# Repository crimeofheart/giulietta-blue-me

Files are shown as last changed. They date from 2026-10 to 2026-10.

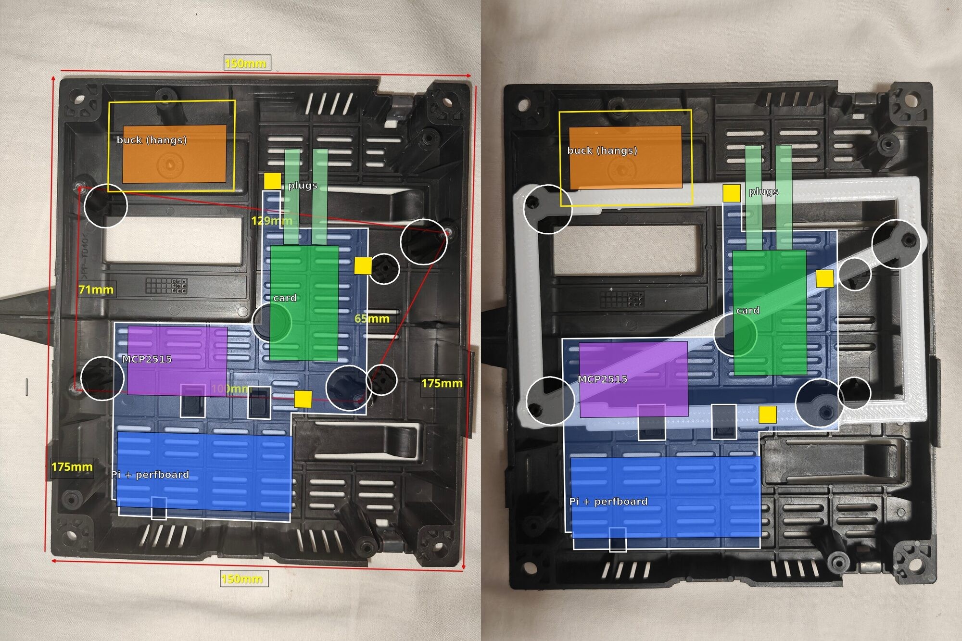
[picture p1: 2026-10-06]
hardware/housing/layout-v2.jpg

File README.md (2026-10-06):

# Blue&Me replacement for the Alfa Romeo Giulietta (940)

A Raspberry Pi Zero W that takes the place of the factory Blue&Me module
(Magneti Marelli 50521871) in an Alfa Romeo Giulietta. It plugs into the car's
own Blue&Me connector, answers the car as that module on the body CAN bus, and
plays the phone's Bluetooth audio through the factory radio. The radio stays.

- Bluetooth music on the radio's Blue&Me source, with artist, title and time on the radio's display
- Hands-free calls through the car's speakers and its own roof microphone (wideband, mSBC)
- Steering-wheel buttons: next, previous, answer, reject, hang up, microphone mute,
  the phone's voice assistant, move a call between car and phone
- The radio's arrow keys: skip a track, Bluetooth volume
- Parked: standby for 72 hours, then a halt; it wakes on bus traffic or on ignition

How it was built, with the wiring, the measurements and the mistakes:
**<https://duzgun.org/blog/giulietta-blue-me/>**

## Status

Installed in one car since 1 October 2026: a 2011 Giulietta 2.0 JTDm with the
standard radio. Everything in the list above works in that car. It has not been
tried on another car, model year or radio.

One difference from the copy that runs in that car: there the car's PROXI value
is built in. Here it is a setting, `can.proxi_value`, because every car has its
own. That setting is covered by the tests, not yet by a drive.

Still open: echo cancellation on the Pi, what the car does when the Pi answers
late after a parking longer than 72 hours, a read-only root filesystem, and the
glovebox USB socket, which the original module powered.

## Read this before you connect anything to a car

- This software transmits on the car's CAN bus. A fresh install does not: it
  only listens until you switch it with `tx.sh on`.
- One step of the build writes a configuration record in the Body Computer, so
  that the car expects the module (`experiments/node61/write_bc_record.py`).
  Read the record first, keep the copy, and understand the step before you run it.
- Every frame the application sends was first recorded from this one car. Your
  car can differ. Record your own car and compare before anything transmits.
- Never use the PROXI value of another car. Use your own (see below).
- 12 V from the car goes only to the step-down converter, behind a fuse.
- There is no warranty. You do this at your own risk.

## Hardware

| Part | Notes |
|---|---|
| Raspberry Pi Zero W | Raspberry Pi OS Lite, Bookworm, 32-bit |
| MCP2515 CAN module with TJA1050 | 8 MHz crystal, 120 Ω terminator removed, transceiver on 5 V and controller on 3.3 V |
| USB sound card, C-Media HS-100B (`0d8c:0014`) | line out to the radio, microphone in from the car |
| 12 V to 5 V step-down converter | has to hold 5 V while the engine starts |
| Perfboard | microphone supply and divider, ignition sense transistor, diode and 2200 µF for engine starts |

Pins used on the Blue&Me connector: 30 CAN high, 14 CAN low, 15 ground,
5 / 22 / 21 audio left / right / ground, 8 / 24 microphone + / −,
16 permanent 12 V, 32 ignition.

The bus is B-CAN at 50 kbit/s with 29-bit identifiers (`topic << 16 | node`).
The module is node `4021`.

## Install

Copy the repository to the Pi and run the installer there (the examples use
the user `admin` and the host name `blueandme`):

```
rsync -a --exclude .git ./ admin@blueandme.local:giulietta-blue-me/
ssh admin@blueandme.local
cd ~/giulietta-blue-me && sudo ./install.sh --oscillator 8000000
```

`--oscillator` is the crystal on your MCP2515 module, 8000000 or 16000000.
The installer sets up the CAN interface, the sound card, Bluetooth audio and the
services, and leaves everything listen-only. Afterwards:

| Command | What it does |
|---|---|
| `blueandme-status` | checks the CAN interface, the sound card and the audio services |
| `sudo ./preflight.sh` | tests the CAN chain on the bench, with no car attached |
| `blueandme-pair` | makes the Pi pairable for the phone |
| `blueandme-capture`, `blueandme-decode`, `blueandme-diff` | record the bus and read the recordings |
| `sudo ./tx.sh on`, `off`, `status` | switch between listening and answering as the module |

The configuration is `/etc/blueandme/config.yaml`; the commented defaults are in
`blueandme/config/default.yaml`.

## From listening to transmitting

1. **Listen.** Record your car with the Pi on the Blue&Me connector and compare
   it with what the post describes.
2. **Your PROXI value.** About a second after the bus wakes, the Body Computer
   sends `1E114000#` and the other modules answer with the same six bytes (in
   my car `1E11400A#…`, `1E114003#…` and `1E11401A#…`). Put those 12 hex digits,
   in quotes, in the configuration as `can.proxi_value`. While it is empty the
   Pi does not answer that question, and a car that expects the module blinks
   its odometer.
3. **Transmit.** `sudo ./tx.sh on` puts the CAN controller in normal mode and
   lets the application send the module's six frames. `tx.sh off` goes back.

Which frames may be sent is not a matter of trust. Each frame in
`blueandme/protocol/profiles/giulietta940.py` names the recording and the moment
it was seen in, and the transmit gate (`blueandme/can/txgate.py`) sends only
frames confirmed on this car, plus exceptions that are named and dated in the
profile. The recordings themselves are of my car and are not published.

## Repository

```
blueandme/          the application
  can/              bus access and the transmit gate
  protocol/         frames with their evidence: the Giulietta, and for comparison
                    only the Fiat Doblò 263 and the Alfa 159
  vehicle/          what the module says on the bus (node.py), wheel buttons, radio text
  media/            Bluetooth: phone link, calls, wheel actions, microphone relay
  power/            standby and ignition
  tools/            capture, decode, diff, status
systemd/  udev/     units and rules that install.sh installs
install.sh          installer for the Pi
preflight.sh        bench test of the CAN chain
tx.sh               listen-only <-> transmitting
experiments/        supervised scripts from the bring-up (read its README first)
hardware/housing/   OpenSCAD models for a carrier inside the original case
packages/           bluez-alsa 4.3.1 with mSBC, built for the Zero W
tests/
```

The housing is unfinished: `board_template` fits the bosses of the original
case, the sled has only been test-printed, and the printed pin holder was not
used in the end (a piece of perfboard carries the header pins).

## Tests

```
python -m venv .venv && .venv/bin/pip install -e '.[dev]'
tests/fixtures/fetch.sh          # optional: the Doblò traces, see tests/fixtures/README.md
.venv/bin/python -m pytest
```

## Thanks

- **fmntf**, for [fiatcan](https://github.com/fmntf/fiatcan) and the
  [four-part write-up on Medium](https://medium.com/@fmntf): the Doblò protocol,
  the node addressing, the PROXI answer taken from the neighbours, the
  wheel-button bits, the text format and the insight about boot timing. This
  build grew out of that work.
- **karolkrupa**, for [alfa-blue-me](https://github.com/karolkrupa/alfa-blue-me):
  the Alfa 159 build, an independent confirmation of the character set, and the
  report that the Giulietta uses 29-bit identifiers.
- **terilenard**, for
  [mcp2515-tja1050-wiring](https://github.com/terilenard/mcp2515-tja1050-wiring):
  the split-rail modification of the CAN module.
- **Arkadiusz Bokowy**, for [bluez-alsa](https://github.com/arkq/bluez-alsa).

## Licence

MIT, see `LICENSE`. The package in `packages/` is a build of bluez-alsa, also
MIT, © Arkadiusz Bokowy (`packages/LICENSE.bluez-alsa`).

This is a private project. It is not affiliated with Alfa Romeo, Fiat,
Stellantis or Magneti Marelli. Blue&Me is a trademark of its owner.

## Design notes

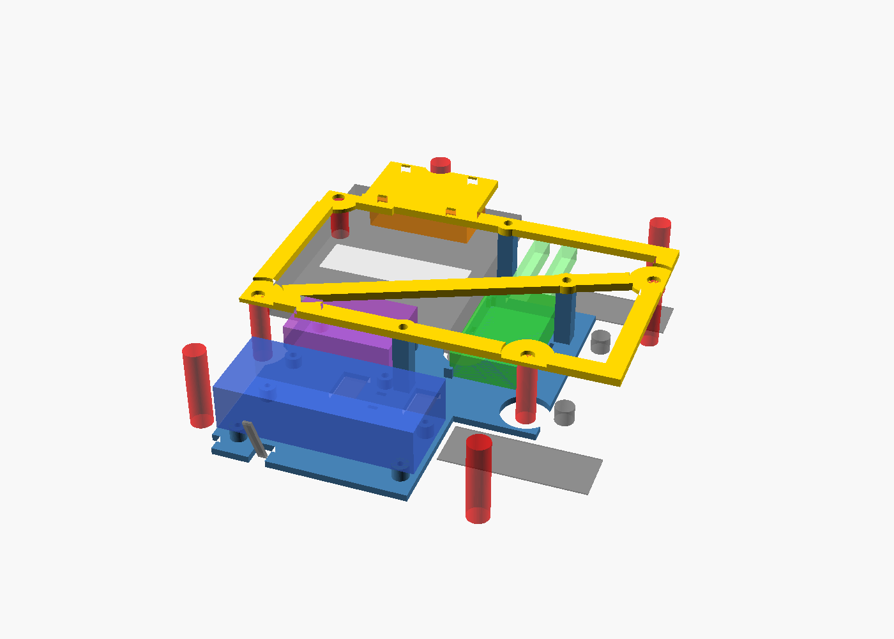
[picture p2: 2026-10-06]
hardware/housing/sled.png

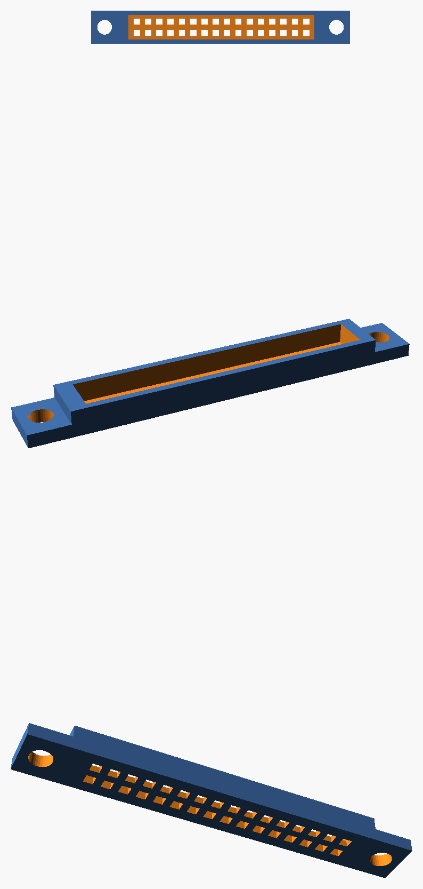
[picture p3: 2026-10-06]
hardware/housing/pin_carrier.png

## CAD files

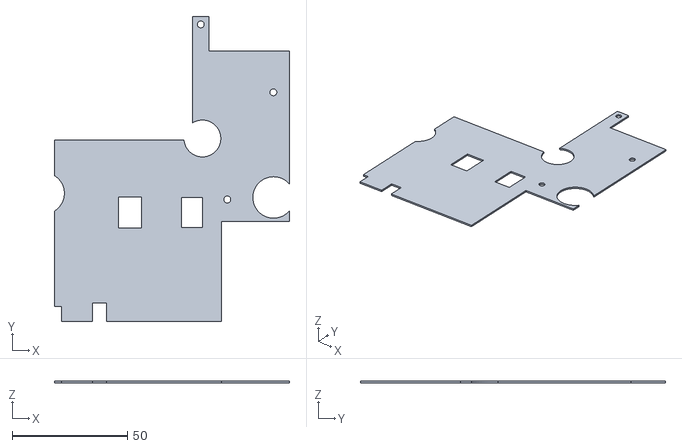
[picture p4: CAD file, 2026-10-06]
hardware/housing/sled_tray_test.stl
102.0 x 132.5 x 0.8

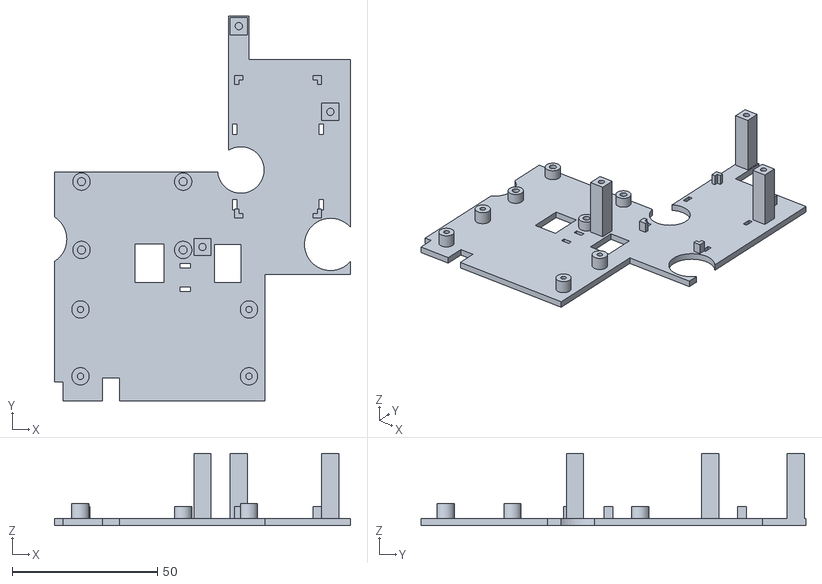
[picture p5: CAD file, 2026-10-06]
hardware/housing/sled_tray.stl
102.0 x 132.5 x 24.8

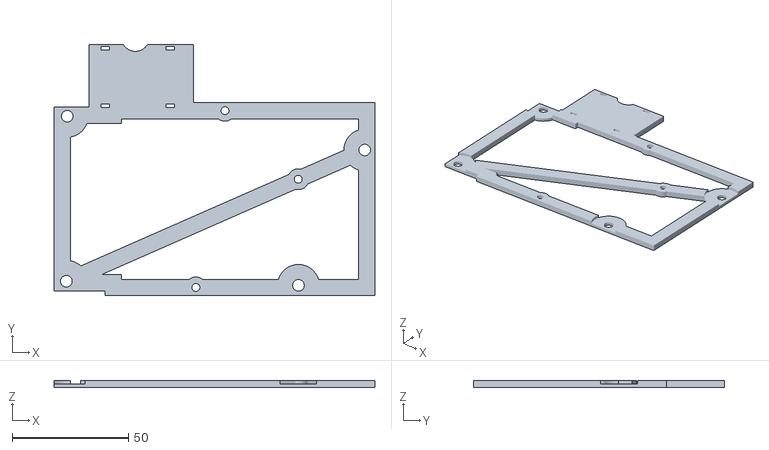
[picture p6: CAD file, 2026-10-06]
hardware/housing/sled_frame.stl
138.0 x 108.0 x 3.00

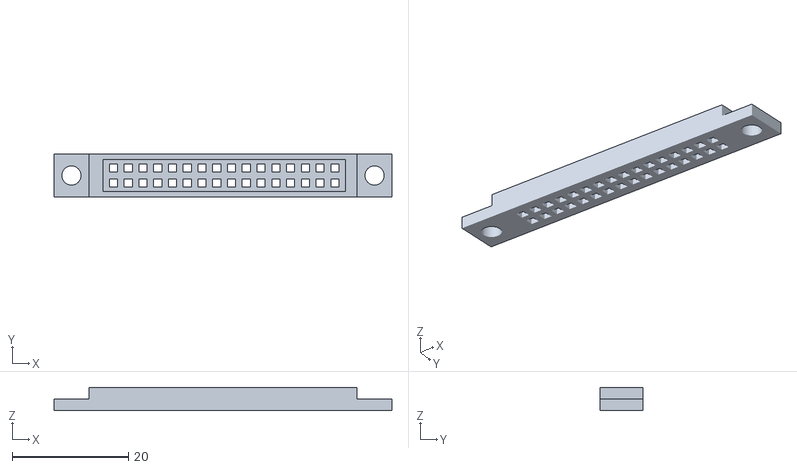
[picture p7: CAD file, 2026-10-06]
hardware/housing/pin_carrier.stl
58.1 x 7.48 x 4.00

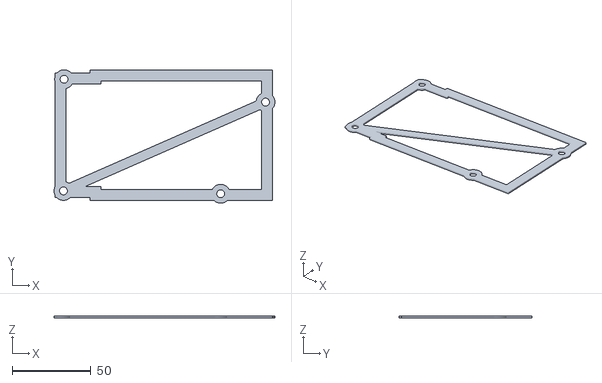
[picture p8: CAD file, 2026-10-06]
hardware/housing/board_template.stl
140.3 x 84.7 x 1.20

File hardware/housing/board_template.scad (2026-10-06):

// Fit template for the Blue&Me case (50521871): the old board's outline and its
// four 5 mm holes, as a thin frame. Print it, drop it onto the four 27 mm bosses
// in the connector half: every boss tip must pass through its hole. If one does
// not, measure how far off it is and correct `holes` below.
//
// Frame: the old board seen from its solder side (the side that faced the lid),
// connector end on the left, origin at the board's bottom-left corner.
// Board: 138 x 83 mm (owner's calipers: 22 + 116 along the long edge, 79 at the
// connector end, 83 at the far end). Holes: fitted to the owner's six caliper
// distances between bosses (sides 71 / 100 / 65 / 129 mm, diagonals H1-H4 123 and
// H2-H3 140 mm; all met within 0.2 mm), the photo only choosing among the fits.
// Turned 1.0 deg anticlockwise (seen from the lid side) about the board centre on
// 2026-09-28: the first print fitted the bosses but sat ~1 deg anticlockwise in
// the case, and the old board's own edges showed the same 1.0 deg against its holes.

board = [138, 83];
step = [22, 2];          // connector end: 79 mm, not 83, over its first 22 mm (2 mm off each long edge)
hole_d = 5;              // old board's holes
holes = [                // [x, y] from the bottom-left corner
    [5.7, 77.1],         // H1  connector end
    [5.3, 6.2],          // H2  connector end
    [133.6, 62.6],       // H3  far end, on the edge
    [105.1, 4.4],        // H4  far end, 29 mm in from the edge
];
t = 1.2;                 // plate thickness
rim = 7;                 // frame width
ring_d = 12;

$fn = 48;

module outline() {
    difference() {
        square(board);
        square(step);
        translate([0, board[1] - step[1]]) square(step);
    }
}

module frame() {
    difference() {
        outline();
        offset(delta = -rim) outline();
    }
}

linear_extrude(t) difference() {
    union() {
        frame();
        for (h = holes) translate(h) circle(d = ring_d);
        // one diagonal brace so the frame stays flat
        hull() { translate(holes[1]) circle(d = 6); translate(holes[2]) circle(d = 6); }
    }
    for (h = holes) translate(h) circle(d = hole_d);
}

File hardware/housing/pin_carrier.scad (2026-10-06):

// Holder for 2 x 16 standard male header pins (2.54 mm, 0.64 mm square pins,
// 2.5 mm plastic spacer): two 1 x 16 strips side by side, or four 1 x 8 strips
// laid two end to end per row (the owner's; the floor holes keep the pitch
// across the joint). Plugs straight into the car's 32-way Blue&Me plug (TE MQS,
// 2 x 16 at 2.54 mm), which gets glued or tied on (owner, 2026-09-28: keep it
// simple).
//
// The floor is the bottom of the holder, with a hole for each pin. The strips
// drop in from the top, tails down through the holes, until their spacers sit
// on the floor; pushing the holder onto the plug, the floor pushes the strips
// with it. The walls stand 0.5 mm above the spacers (4.0 mm from the bottom,
// owner), so the plug's face rests on the walls and the pins reach 0.5 mm less
// deep than on the spacers. Wires solder to the tails sticking out under the
// floor; a drop of glue there afterwards.
// No printed marks (they failed on a 0.6 mm nozzle): mark pins 1 and 17 with a
// pen, and put them to the corner of the plug moulded "1" / "17".
//
// Frame: X along the strips from the pin 16/32 end (the thicker end), Y across,
// Z up (mating side up, print this way).

pitch = 2.54;
spacer = [16 * pitch, 2 * pitch, 2.5];   // two rows side by side
fit = [1.1, 0.4];                        // slack round the spacers: 0.5 mm more lengthwise, the
                                         // owner's strips' plastic runs past the end pins
pocket = [spacer[0] + fit[0], spacer[1] + fit[1], spacer[2] + 0.5];   // walls 0.5 mm above the spacers (owner)
wall = 1.0;                              // long sides
end_wall = [2.4, 2.0];                   // pin 16/32 end 0.4 mm thicker than the pin 1/17 end,
                                         // as on the original (4.6 vs 4.2 mm to the nearest pin)
floor_t = 1.0;                           // leaves 2 mm of a standard 3 mm tail below it
tail_hole = 1.4;                         // square holes for 0.64 mm square tails: square for a
                                         // 0.6 mm nozzle, 1.14 mm (two lines) of floor between them
ear = [6, 2, 3.3];                       // length, thickness, M3 hole

outer = [pocket[0] + end_wall[0] + end_wall[1], pocket[1] + 2 * wall, floor_t + pocket[2]];
$fn = 32;

difference() {
    union() {
        cube(outer);
        for (x = [-ear[0], outer[0] - 0.5]) translate([x, 0, 0]) difference() {
            cube([ear[0] + 0.5, outer[1], ear[1]]);                      // 0.5 into the body
            translate([x < 0 ? ear[0] / 2 : ear[0] / 2 + 0.5, outer[1] / 2, -1]) cylinder(d = ear[2], h = ear[1] + 2);
        }
    }
    // pocket for the spacers, down to the floor
    translate([end_wall[0], wall, floor_t]) cube([pocket[0], pocket[1], pocket[2] + 1]);
    // a square hole through the floor for each pin, 2 x 16 round the pocket centre
    for (k = [0:15], row = [-1, 1])
        translate([end_wall[0] + pocket[0] / 2 + (k - 7.5) * pitch, wall + pocket[1] / 2 + row * pitch / 2, -1])
            translate([-tail_hole / 2, -tail_hole / 2, 0]) cube([tail_hole, tail_hole, floor_t + 2]);
}

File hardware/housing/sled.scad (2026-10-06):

// Sled for the Blue&Me case: everything inside the original case, no drilling.
//
//   frame  flat ring at the old board's level, on all four bosses; the lid posts
//          and case screws clamp it there as they clamped the board (1.6 mm pads).
//          A plate on its connector side carries the buck, hanging under it on
//          two zip ties, over the raised floor.
//   tray   on the case floor ribs, parts facing up, with three posts that the
//          frame screws onto (M3 from the top), so tray + frame are one rigid unit
//
// All print flat without supports: part = "tray" / "frame" / "tray_test";
// "assembly" shows them in place with the parts as boxes. tray_test is the tray's
// outline and cut-outs as a 0.8 mm sheet: lay it in the case first, it must lie
// flat on the ribs and every floor feature must come through its hole.
//
// Frame: the board frame from board_template.scad (lid view, x from the connector
// end, y across, origin the old board's bottom-left corner); z up from the top of
// the floor ribs (boss tips at 25). Floor features from two photos of the case
// (the bare case at ~15 cm, the template on the bosses at ~30 cm), each posed on
// the four boss tips and projected down to the floor, not the tips' plane (the
// first model did that: up to 9 mm off). The two photos agree within ~2 mm.
// Corrected from a third photo of the printed tray_test in the case (2026-09-28,
// camera and sheet fitted together, 0.5 mm rms): snap tabs, wall blade, disc.
// Then from the v2 sheet (photo 192939, 0.3 mm rms): step base, left wall line,
// blade, disc, clips; the sheet lay ~0.8 mm / 0.75 deg off, pushed by the step.

part = "assembly";

// ---- case ---------------------------------------------------------------
bosses = [[5.7, 77.1], [5.3, 6.2], [105.1, 4.4], [133.6, 62.6]];   // H1 H2 H4 H3
boss_z = 25;                    // floor ribs to boss tips
boss_keep = 9;                  // boss with its fins
raised = [68, 30.3, 10];        // connector corner: floor 10 mm higher for x < 68, y > 30.3 (step base)
plug_window = [7.2, 53, 62.6, 70.1];            // in the raised floor: the car's plug comes in here
tongues = [[84.1, 69.7, 137.3, 86.4], [84.1, -26.2, 135.9, -7.9]];   // flex outward
latches = [[38.8, -7.8, 46.8, 3.5], [66.1, -7.7, 73.2, 3.3]];        // snap clips in floor holes, 1.3 mm tall (owner)
cross_pins = [[118.3, 51.8], [117.8, 7.9]];     // cross-shaped pins, ~7 mm across
disc = [74.2, 30.0];            // round floor pad, ~12 mm across
wall_blade = [28, -54, 31, -44.5];   // slanted vent blade on the far wall, reaches the floor at y -44.5
case_posts = [[35, 111], [127.5, 96], [2, -35], [106, -48]];   // full-height, with fins
keep = 1;                       // clearance round all of the above (the photos are +-1-2 mm)

// ---- frame --------------------------------------------------------------
board = [138, 83];
step = [22, 2];                 // old board 79 mm over its first 22 mm
beam_w = 7;
beam_t = 3.0;                   // lid is 1.6 + 5 mm above the boss tips
pad_d = 18;                     // lid posts are 15 across
pad_t = 1.6;                    // as the old board
boss_hole = 5;                  // as the old board: case screws pass through
brace_w = 7;
buck_plate = [15, 76, 60, 108]; // over the raised floor, beside the plug window

// ---- tray ---------------------------------------------------------------
tray_t = 2.5;
tray_outline = [[13, -49.5], [82.5, -49.5], [82.5, -6], [112, -6], [112, 68], [77, 68], [77, 83],
                [70, 83], [70, 29.3], [10, 29.3], [10, -43], [13, -43]];   // >= 1 mm off the step and the walls
test_t = 0.8;                   // tray_test thickness
blade_notch = 8;                // notch for the wall blade, depth from the tray's far edge (owner)
post_xy = [[61, 3.5], [105, brace_y(105)], [73.5, 79.5]];   // under the bottom beam (between the clips, clear of
                                // the card's cable), the brace, the top beam
post_w = 6;
post_gap = 0.2;                 // posts a hair short: the frame seats on the bosses, not the posts
pilot_d = 2.5;                  // M3 into PETG
slot = [1.6, 3.6];              // zip-tie slot

// ---- parts (x0, y0, x1, y1) ------------------------------------------------
pi = [15.5, -44.5, 80.5, -14.5];    // Pi Zero 65 x 30, header to the far wall, SD end right, ports up (+y):
                                    // PWR at x 26.5, OTG at x 39 (unused: the card's cable is soldered to
                                    // the test pads underneath, owner 2026-09-29);
                                    // 2.8 mm clear of the wall blade at the Pi's underside
perf = [13, -44.5, 83, -14.5];  // 30 x 70 perfboard on its header
pi_holes = [[3.5, 3.5], [61.5, 3.5], [3.5, 26.5], [61.5, 26.5]];
pi_standoff = 5;                // room under it for the pad joints and the card's wires
cable_tie = [55, -7];           // tie point for the card's cable, between the Pi and the MCP
mcp = [17, 0.5, 56.7, 28];      // MCP2515 39.7 x 27.5, CAN terminal left (to the plug window)
mcp_holes = [[2.35, 2], [37.35, 2], [2.35, 25.5], [37.35, 25.5]];   // 35 x 23.5 centre to centre, holes 4 mm (owner): M3
mcp_standoff = 4;               // room for its solder tails; passes over the 1.3 mm clip
card = [73.5, 15, 100.5, 61];   // sound card 27 x 46, jacks up (+y), cable down
plugs = [[78.5, 84.5], [89.5, 95.5]];   // x ranges of the two 3.5 mm plugs, 38 mm long
card_ties = [18, 44];           // y of the zip ties across it (clear of the disc hole)
buck = [16, 83, 56, 105];       // buck 40 x 22 x 12, no holes: hangs under buck_plate
buck_ties = [22, 50];           // x of the zip ties across it
standoff_d = 6;

$fn = 48;

function brace_y(x) = 6.2 + (x - 5.3) * (62.6 - 6.2) / (133.6 - 5.3);

module board_outline() {
    difference() { square(board); square(step); translate([0, board[1] - step[1]]) square(step); }
}

module frame() {
    difference() {
        linear_extrude(beam_t) difference() {
            union() {
                intersection() {                // nothing past the old board's edge: it hits the case walls (owner)
                    board_outline();
                    union() {
                        difference() { board_outline(); offset(delta = -beam_w) board_outline(); }
                        hull() { translate(bosses[1]) circle(d = brace_w); translate(bosses[3]) circle(d = brace_w); }
                        for (b = bosses) translate(b) circle(d = pad_d);
                        for (p = post_xy) translate(p) circle(d = 9);
                    }
                }
                difference() {
                    translate([buck_plate[0], buck_plate[1]]) square([buck_plate[2] - buck_plate[0], buck_plate[3] - buck_plate[1]]);
                    translate(case_posts[0]) circle(r = 6);
                }
            }
            // zip ties round the buck, across its width
            for (x = buck_ties, y = [buck[1] - slot[0] - 0.6, buck[3] + 0.6])
                translate([x - slot[1] / 2, y]) square([slot[1], slot[0]]);
        }
        // pads: 1.6 mm under the lid posts
        for (b = bosses) translate([b[0], b[1], pad_t]) cylinder(d = pad_d + 0.01, h = beam_t);
        for (b = bosses) translate([b[0], b[1], -1]) cylinder(d = boss_hole, h = beam_t + 2);
        for (p = post_xy) translate([p[0], p[1], -1]) cylinder(d = 3.4, h = beam_t + 2);
    }
}

module rect(r, grow = 0) {
    translate([r[0] - grow, r[1] - grow]) square([r[2] - r[0] + 2 * grow, r[3] - r[1] + 2 * grow]);
}

module tray_2d() {
    difference() {
        polygon(tray_outline);
        for (b = bosses) translate(b) circle(r = boss_keep);
        for (t = concat(tongues, latches)) rect(t, keep);
        for (p = cross_pins) translate(p) circle(r = 6);      // 3.5 + keep + their unknown height
        translate(disc) circle(r = 8);
        translate([wall_blade[0] - keep - 0.5, tray_outline[0][1] - 1])
            square([wall_blade[2] - wall_blade[0] + 2 * keep + 1, blade_notch + 1]);
        for (p = case_posts) translate(p) circle(r = 5);
    }
}

module zip_slots(x0, x1, y) {           // a pair either side of a part, tie across it
    for (x = [x0 - slot[0] - 0.6, x1 + 0.6]) translate([x, y - slot[1] / 2, -1]) cube([slot[0], slot[1], tray_t + 2]);
}

module standoff(xy, h, hole) {
    translate([xy[0], xy[1], 0]) difference() {
        cylinder(d = standoff_d, h = tray_t + h);
        translate([0, 0, 1]) cylinder(d = hole, h = tray_t + h);
    }
}

module corner_stops(r, h) {             // L-shaped stops holding a part's four corners
    for (cx = [0, 1], cy = [0, 1]) {
        x = cx ? r[2] : r[0];
        y = cy ? r[3] : r[1];
        translate([x - 1.5, y - 1.5, 0]) difference() {
            cube([3, 3, tray_t + h]);
            translate([cx ? -0.01 : 1.5, cy ? -0.01 : 1.5, tray_t]) cube([1.51, 1.51, h + 1]);
        }
    }
}
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

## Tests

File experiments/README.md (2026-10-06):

# experiments/

Scripts from the bring-up, each run by hand, at the car, with someone watching.
They are **outside the application's transmit gate**: they send what they are
told to send. They are published because the build cannot be repeated without
them, not because they are safe to run blindly.

Before running any of them:

- Read the script. Each one says at the top what it sends and why.
- Every script that transmits refuses to start without `--transmit`.
- Unplug the original Blue&Me module first. Two nodes with the same address contend.
- The values in them were measured on one car, a 2011 Giulietta 2.0 JTDm.

| Folder | What it is |
|---|---|
| `node61/node61_responder.py` | answers the diagnostic tester as the telematic node (`61`) during a PROXI alignment, and saves the record the tester writes |
| `node61/write_bc_record.py` | reads or writes record `2023` of the Body Computer. `--read-only` reads it. **Writing changes the car's configuration**: read first, keep that file, it is your way back |
| `node4021/node4021_full.py` | answers the car as the Blue&Me node (`4021`). The application does this now (`vehicle/node.py`); the script remains for tests the application does not have, such as `--glyph-test`. Needs `--value`, your car's PROXI value |
| `node4021/car_tx.sh` | runs that script at the car and puts the CAN interface back as it found it |
| `node4021/app_replay.sh` | bench: replays a recording to the installed application on `vcan0` |
| `node4021/scroll_test.py` | sends extra track text to the radio |
| `wheel/press.sh` | bench: presses a steering-wheel button through the CAN controller's loopback |
| `standby/` | standby simulations and the power measurements behind the 72-hour hold |

The `test_*.py` files next to the scripts check them on a virtual bus and need
no car: `python experiments/node61/test_node61.py`.

The scripts name recordings (`captures/...`) as the source of what they send.
Those are recordings of my car and are not published.

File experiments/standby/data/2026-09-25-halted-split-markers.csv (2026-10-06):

unix_time,marker
1790343485.339,R running, idle, phone connected (reference)
1790343523.505,H1 halted, everything attached
1790343690.776,H2 halted, sound card unplugged
1790343779.641,H3 halted, card unplugged, CAN board 5 V off
1790343867.020,H4 halted, bare Pi (card, CAN 5 V and 3.3 V off)
1790343991.145,U unplugged to reconnect the parts
1790344038.169,"B power back: cold boot, everything attached"

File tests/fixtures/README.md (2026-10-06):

# tests/fixtures/

The decoder and the diff tool are tested against real traffic: three recordings
of a Fiat Doblò from [fmntf/fiatcan](https://github.com/fmntf/fiatcan)
(`Traces/`), each with fmntf's own decoding next to it.

fiatcan is published without a licence, so the recordings are not copied into
this repository. `fetch.sh` downloads the first 2000 lines of each from a fixed
commit of fiatcan:

```
tests/fixtures/fetch.sh
```

Without them the tests that need them are skipped; everything else runs.

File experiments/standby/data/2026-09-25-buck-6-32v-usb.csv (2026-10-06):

unix_time | volts | amps | watts
1790359859.120 | 4.9119 | 0.2291 | 1.1257
1790359859.300 | 4.9121 | 0.1879 | 0.9232
1790359859.615 | 4.9121 | 0.2019 | 0.9918
1790359859.795 | 4.9124 | 0.1995 | 0.9800
1790359860.111 | 4.9126 | 0.1971 | 0.9684
1790359860.290 | 4.9127 | 0.1961 | 0.9635
1790359860.605 | 4.9129 | 0.1931 | 0.9488
1790359860.786 | 4.9129 | 0.1925 | 0.9460
1790359861.146 | 4.9130 | 0.1924 | 0.9452
1790359861.326 | 4.9130 | 0.1923 | 0.9449
1790359861.595 | 4.9130 | 0.1922 | 0.9445
1790359861.820 | 4.9129 | 0.1921 | 0.9441
1790359862.135 | 4.9130 | 0.1921 | 0.9441
1790359862.316 | 4.9130 | 0.1922 | 0.9443
1790359862.585 | 4.9130 | 0.1922 | 0.9447
1790359862.810 | 4.9130 | 0.1922 | 0.9444
1790359863.126 | 4.9131 | 0.1923 | 0.9448
1790359863.305 | 4.9130 | 0.1923 | 0.9452
1790359863.620 | 4.9130 | 0.1924 | 0.9457
1790359863.800 | 4.9131 | 0.1924 | 0.9453
1790359864.115 | 4.9131 | 0.1920 | 0.9436
1790359864.340 | 4.9130 | 0.1922 | 0.9443
1790359864.610 | 4.9130 | 0.1923 | 0.9447
1790359864.791 | 4.9130 | 0.1922 | 0.9445
1790359865.105 | 4.9130 | 0.1928 | 0.9473
1790359865.285 | 4.9130 | 0.1927 | 0.9468
1790359865.600 | 4.9130 | 0.1925 | 0.9458
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

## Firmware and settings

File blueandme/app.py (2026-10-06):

"""blueandme-giulietta -- the service.

Wires the CAN side, the vehicle logic and Bluetooth together and runs the
cyclic transmit loop. On a stock install this process starts, opens the bus in
listen-only mode, decodes what it can, transmits nothing, and says so clearly in
the journal. That is the intended behaviour until the Giulietta profile has been
populated from real captures.
"""

from __future__ import annotations

import argparse
import logging
import sys
import threading
import time
from pathlib import Path

from .can.bus import CanBus, ReceivedFrame
from .can.dispatcher import Dispatcher
from .can.txgate import CanMode, TransmitRefused, TxGate
from .config import Config, load
from .events import EventBus
from .power.ignition import IgnitionMonitor
from .power.lifecycle import Lifecycle
from .protocol.registry import get
from .vehicle import presence as presence_mod
from .vehicle import proxi as proxi_mod
from .vehicle import node as node_mod
from .vehicle.display import Display
from .vehicle.presence import Presence
from .vehicle.proxi import ProxiResponder
from .vehicle.radio import AudioChannel, Radio
from .vehicle.steering_wheel import SteeringWheel

log = logging.getLogger("blueandme.app")


def has_wheel(profile) -> bool:
    """Whether the profile knows the wheel's button frame and its masks."""
    return "steering_wheel_buttons" in profile and bool(profile.buttons)


def caller_text(calls) -> "str | None":
    """Who to show on the cluster: the ringing or waiting call first."""
    from .media.wheel_control import INCOMING, WAITING

    if not calls:
        return None
    ringing = [c for c in calls if c.status in (INCOMING, WAITING)]
    call = (ringing or calls)[0]
    return call.name or call.number or "CALL"


def has_node(profile) -> bool:
    """Whether the profile has every frame node 4021 speaks (the Giulietta's)."""
    return all(name in profile for name in (*node_mod.RX_FRAMES, *node_mod.TX_FRAMES))

CYCLE_S = 1.0
#: How often the phone's calls and track are read while the car is awake.
PHONE_POLL_S = 2.0


class Application:
    def __init__(self, cfg: Config, phone: bool = True) -> None:
        self.cfg = cfg
        self.profile = get(cfg.can.profile)
        self.events = EventBus()
        self.gate = TxGate(
            self.profile,
            cfg.can.mode,
            cfg.can.min_tx_confidence,
            cfg.can.allowed_tx_frames,
        )
        self.bus = CanBus(cfg.can.interface, self.profile, self.gate, cfg.can.bitrate,
                          filter_to_profile=has_node(self.profile))
        self.dispatcher = Dispatcher(self.profile)
        self.presence = Presence(self.profile, self.events)
        self.proxi = ProxiResponder(self.profile, self.events)
        self.radio = Radio(self.profile, self.events)
        self.display = Display(self.profile)
        self.wheel = SteeringWheel(self.profile, self.events)
        self.ignition = IgnitionMonitor(
            self.events, cfg.power.stay_awake_after_key_off_s,
            cfg.power.shutdown_delay_s,
        )
        self.lifecycle = Lifecycle()
        self.media = None
        self.phone = None
        self.wheel_control = None
        if phone and has_wheel(self.profile):
            from .media.wheel_control import BluetoothPhone, WheelControl

            # The wheel drives the phone over Bluetooth only, so it runs in
            # every CAN mode, listen-only included.
            self.phone = BluetoothPhone()
            self.wheel_control = WheelControl(self.events, self.phone)
        # Node 4021 as this car accepted it (vehicle/node.py). The Doblo-rule
        # presence, PROXI and radio modules above serve the reference profiles.
        self.node = node_mod.BlueAndMeNode(self.events, self._node_send,
                                           proxi_value=cfg.can.proxi_bytes()) \
            if has_node(self.profile) else None
        self._not_sent: set[str] = set()
        self._halt_deferred = False
        self._running = False
        self._subscribe()

    # -- wiring ------------------------------------------------------------

    def _subscribe(self) -> None:
        p = self.profile
        if "steering_wheel_buttons" in p:
            self.dispatcher.on("steering_wheel_buttons", self.wheel.on_frame)
        if self.node is not None:
            for name in (*node_mod.RX_FRAMES, "steering_wheel_buttons"):
                self.dispatcher.on(name, self.node.on_frame)
        elif presence_mod.RX_NETWORK_CONTROL in p:
            self.dispatcher.on(presence_mod.RX_NETWORK_CONTROL, self.presence.on_frame)
        for name in (proxi_mod.RX_REQUEST, *proxi_mod.PEER_FRAMES):
            if name in p:
                self.dispatcher.on(name, self.proxi.observe)
        if "radio_frequency" in p:
            self.dispatcher.on("radio_frequency", self.radio.on_frame)
        self.dispatcher.on_unmatched(self._unknown)

        self.events.on("media_playing", self._on_playing)
        self.events.on("media_position", self._on_position)
        self.events.on("media_skipped", self._on_skipped)
        self.events.on("audio_channel", self._on_radio_source)
        self.events.on("sleep_requested", self._on_sleep)

    def _unknown(self, frame: ReceivedFrame) -> None:
        log.debug("unrecognised %s#%s", frame.hex_id, frame.data.hex().upper())

    # -- bluetooth ---------------------------------------------------------

    def start_bluetooth(self) -> None:
        from .media.bluez import BluetoothMedia
        from .media import pairing

        try:
            pairing.register(self.cfg.bluetooth.name, self.cfg.bluetooth.pairable)
        except Exception:
            log.exception("pairing agent registration failed; continuing")
        self.media = BluetoothMedia(
            self.events,
            self.cfg.bluetooth.reconnect_interval_s,
            self.cfg.bluetooth.auto_reconnect,
        )
        self.media.start()

    # -- event handlers ----------------------------------------------------

    def _on_playing(self, playing: bool) -> None:
        self.radio.set_channel(AudioChannel.MEDIA if playing else AudioChannel.MUTED)

    def _on_skipped(self, action: str) -> None:
        if action == "previous" and self.node is not None:
            self.node.track_restarted()

    def _on_position(self, seconds: int) -> None:
        # fiatcan guards against phones that report absurd positions.
        if 0 <= seconds < 60 * 60:
            self.radio.track_position_s = seconds

    def _on_radio_source(self, source: str) -> None:
        """The driver changed source on the head unit; follow it."""
        if self.phone is not None:
            # Off the receive thread: a D-Bus round trip on the Zero W must not
            # hold up the next answer to the car.
            action = "play" if source == "bm" else "pause"
            threading.Thread(target=self.phone.media, args=(action,),
                             name="radio-source", daemon=True).start()
            return
        if self.media is None:
            return
        if source == "bm":
            self.media.play()
        else:
            self.media.pause()

    def _on_sleep(self) -> None:
        log.info("sleep requested by the vehicle")

    # -- cyclic transmit ---------------------------------------------------

    def _cycle(self) -> None:
        """One pass of the 1 Hz loop. Every send goes through TxGate."""
        if self.node is not None:
            self.node.tick()
            return
        self._try_send(presence_mod.TX_STATUS, self.presence.status_payload())
        payload = self.proxi.response_payload()
        if payload is not None and self.proxi.challenges_seen:
            if self._try_send(proxi_mod.TX_RESPONSE, payload):
                self.proxi.answered()
        self._try_send("bm_audio_channel", self.radio.audio_channel_payload())
        self._try_send("bm_track_time", self.radio.track_time_payload())

    def _node_send(self, frame_name: str, payload: bytes) -> bool:
        """Send for the node, quietly: in listen-only, or before a frame is on
        the gated-tx allow-list, it says so once rather than every second."""
        spec = self.profile.require(frame_name)
        why = self.gate.refusal(spec, payload)
        if why is not None:
            if frame_name not in self._not_sent:
                self._not_sent.add(frame_name)
                log.info("not sending %s: %s", frame_name, why)
            return False
        return self._try_send(frame_name, payload)

    def _try_send(self, frame_name: str, payload: "bytes | None") -> bool:
        if payload is None or frame_name not in self.profile:
            return False
        try:
            self.bus.send(frame_name, payload)
            return True
        except TransmitRefused:
            return False  # already logged by the gate

    # -- run ---------------------------------------------------------------

    def run(self) -> int:
        problems = self.cfg.validate()
        for problem in problems:
            log.error("config: %s", problem)
        if problems and self.cfg.can.mode is not CanMode.LISTEN_ONLY:
            log.error("refusing to start in a transmitting mode with config problems")
            return 2

        log.info("profile %r, %s", self.profile.key, self.gate.describe())
        if (self.node is not None and self.node.proxi_value is None
                and self.cfg.can.mode is not CanMode.LISTEN_ONLY):
            log.warning(
                "can.proxi_value is not set: the Body Computer's PROXI challenge "
                "will not be answered, and a car that expects this node blinks "
                "its odometer"
            )
        if self.profile.extended_ids is None:
            log.warning(
                "profile %s has not resolved 11-bit vs 29-bit addressing "
                "(decision gate D1). Running as a listener only.",
                self.profile.key,
            )

        self.lifecycle.install_signal_handlers()
        self.lifecycle.on_stop(self._stop)
        self._running = True

        with self.bus:
            if self.node is not None:
                # Pairing and reconnecting belong to blueandme-pair and
                # blueandme-bt-reconnect; the wheel and the radio reach the
                # phone through self.phone.
                pass
            elif self.cfg.can.mode is not CanMode.LISTEN_ONLY:
                self.start_bluetooth()
            else:
                log.info("listen-only: Bluetooth stack not started")
            threading.Thread(target=self._rx_loop, name="can-rx", daemon=True).start()
            if self.node is not None and self.phone is not None:
                threading.Thread(target=self._phone_loop, name="phone-poll",
                                 daemon=True).start()
                threading.Thread(target=self._scroll_loop, name="text-scroll",
                                 daemon=True).start()
            self._tx_loop()
        return 0

    def _rx_loop(self) -> None:
        failing = False
        while self._running:
            try:
                frame = self.bus.recv(0.5)
            except Exception as exc:
                # can0 taken down and up (preflight, car_tx.sh, a bus-off): the
                # socket keeps its interface, so wait and read on rather than
                # let the thread die and the wheel go quiet.
                if not failing:
                    log.warning("CAN receive failed (%s); retrying", exc)
                    failing = True
                time.sleep(1.0)
                continue
            if failing:
                log.info("CAN receive working again")
                failing = False
            if frame is not None:
                self.dispatcher.dispatch(frame)

    def _scroll_loop(self) -> None:
        """The radio's running title, a step every TEXT_SCROLL_S."""
        from .protocol.profiles import giulietta940 as P

        next_at = time.monotonic()
        while self._running:
            next_at = max(next_at + P.TEXT_SCROLL_S, time.monotonic())
            time.sleep(max(0.0, next_at - time.monotonic()))   # the clock moved on
            try:
                self.node.scroll()
            except Exception:
                log.exception("text scroll failed")

    def _phone_loop(self) -> None:
        """Calls, track and position into the node, while the car is awake."""
        while self._running:
            time.sleep(PHONE_POLL_S)
            if not self.node.periodic:
                continue   # parked or on the bench: nothing to show anyone
            try:
                calls = self.phone.calls(quiet=True)
                track, position, playing = self.phone.player()
                assistant = self.wheel_control is not None and self.wheel_control.assistant
                self.node.track = track
                self.node.caller = caller_text(calls)
                self.node.set_phone(bool(calls), assistant, position, playing)
            except Exception:
                log.exception("phone poll failed")

    def _tx_loop(self) -> None:
        next_tick = time.monotonic()
        while self._running:
            self._cycle()
            if self.ignition.should_shut_down():
                if self.cfg.power.standby:
                    # blueandme-standby owns power while parked (2026-09-25):
                    # halting here would end the hold the car's PROXI needs.
                    if not self._halt_deferred:
                        log.info("ignition off; standby keeps the Pi up, not halting")
                        self._halt_deferred = True
                else:
                    log.info("ignition off long enough; halting")
                    self.lifecycle.halt()
                    break
            else:
                self._halt_deferred = False
            next_tick += CYCLE_S
            time.sleep(max(0.0, next_tick - time.monotonic()))

    def _stop(self) -> None:
        self._running = False
        if self.media is not None:
            self.media.stop()


def build_parser() -> argparse.ArgumentParser:
    p = argparse.ArgumentParser(
        prog="blueandme-giulietta",
        description="Blue&Me replacement service for the Alfa Romeo Giulietta 940.",
    )
    p.add_argument("--config", type=Path)
    p.add_argument("--log-level", default=None)
    p.add_argument(
        "--check", action="store_true",
        help="validate the configuration and exit without touching the bus",
    )
    p.add_argument(
        "--no-phone", action="store_true",
        help="leave the phone alone: no wheel actions, no play/pause on the "
             "radio's source (for bench replays of captures)",
    )
    return p


def main(argv: "list[str] | None" = None) -> int:
    args = build_parser().parse_args(argv)
    cfg = load(args.config)
    logging.basicConfig(
        level=getattr(logging, (args.log_level or cfg.log_level).upper(), logging.INFO),
        format="%(asctime)s %(levelname)-7s %(name)-18s %(message)s",
    )
    if args.check:
        problems = cfg.validate()
        for problem in problems:
            print(f"PROBLEM: {problem}", file=sys.stderr)
        print("configuration is valid" if not problems else f"{len(problems)} problem(s)")
        return 1 if problems else 0
    try:
        return Application(cfg, phone=not args.no_phone).run()
    except KeyboardInterrupt:
        return 0


if __name__ == "__main__":
    raise SystemExit(main())

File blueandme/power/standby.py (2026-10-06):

"""Standby while parked: the Pi stays up, lean, and wakes with the car.

Decided 2026-09-25 (owner): parked, the Pi stays on in standby for up to 72
hours, then halts; it wakes on CAN traffic and on the ignition, both sensed so
that either can be relied on later. The power latch is shelved. A running Pi answers the Body
Computer's PROXI check in milliseconds, which a cold boot cannot (gate D3), and
gets the phone back far sooner.

Measured on the bench (experiments/standby/, FNB58 at the Pi's 5 V input):

    working, phone connected       1.01 W
    parked, as before standby      1.00 W   (paging the phone every 20 s)
    standby: Bluetooth, Wi-Fi off,
      CPU powersave, LED off       0.63 W   about 65 mA from the car at 12.4 V
    halted                         0.22 W   and only a cold boot gets it back
    wake: CAN frame -> music 8.4 s, calls 9.1 s  (cold power-on: 33.5 / 34.2 s)

72 h of standby is about 4.7 Ah, some 7 % of a 70 Ah battery. At the end of
the hold this service powers off, which on a Zero W is a firmware halt at
about 25 mA from the car (0.6 Ah a day). A halted Zero W boots again when GPIO3
(header pin 5) is pulled low, so the ignition sense goes on GPIO3: key on is a
cold boot. If a power latch is ever fitted (``poweroff_gpio``,
dtoverlay=gpio-poweroff), the kernel raises that line once halted and the latch
cuts the rest. ``--bench`` runs only log the halt.

The policy is armed only once a car has been seen (a frame from a bus, or the
ignition on), so a Pi on the bench, where the bus is always quiet, never goes
lean and never switches its own Wi-Fi off. Frames the Pi sent itself, and
frames looped back by the controller (preflight.sh), do not arm or wake it.
"""

from __future__ import annotations

import argparse
import logging
import os
import re
import signal
import subprocess
import time
from enum import Enum
from pathlib import Path
from typing import Callable

log = logging.getLogger("blueandme.standby")


class State(Enum):
    AWAKE = "awake"
    STANDBY = "standby"
    HOLD_OVER = "hold over"


class Action(Enum):
    ENTER = "enter standby"
    WAKE = "wake"
    POWER_OFF = "power off"


class StandbyPolicy:
    """When to go lean, when to wake, when the hold is over. No side effects."""

    def __init__(self, quiet_s: float, hold_s: float,
                 clock: Callable[[], float] = time.monotonic) -> None:
        self.quiet_s, self.hold_s, self.clock = quiet_s, hold_s, clock
        self.state = State.AWAKE
        self.armed = False
        self.ignition_on = False
        self.last_activity = clock()
        self.standby_since: float | None = None

    def on_frame(self) -> "Action | None":
        """A frame from the car's bus."""
        self.last_activity = self.clock()
        if not self.armed:
            self.armed = True
            log.info("car seen on CAN; standby armed")
        return self._wake("CAN traffic")

    def on_ignition(self, on: bool) -> "Action | None":
        if on == self.ignition_on:
            return None
        self.ignition_on = on
        self.last_activity = self.clock()
        log.info("ignition %s", "on" if on else "off")
        if on:
            self.armed = True
            return self._wake("ignition")
        return None

    def tick(self) -> "Action | None":
        now = self.clock()
        if self.state is State.AWAKE:
            if (self.armed and not self.ignition_on
                    and now - self.last_activity >= self.quiet_s):
                self.state, self.standby_since = State.STANDBY, now
                return Action.ENTER
        elif self.state is State.STANDBY:
            if now - self.standby_since >= self.hold_s:
                self.state = State.HOLD_OVER
                return Action.POWER_OFF
        return None

    def _wake(self, why: str) -> "Action | None":
        if self.state is State.AWAKE:
            return None
        log.info("waking: %s", why)
        self.state, self.standby_since = State.AWAKE, None
        return Action.WAKE


# -- the system: what going lean and waking up actually switch --------------

GOVERNOR = Path("/sys/devices/system/cpu/cpu0/cpufreq/scaling_governor")
ACT_LED = Path("/sys/class/leds/ACT")


def _run(*cmd: str, timeout: float = 30) -> subprocess.CompletedProcess:
    try:
        return subprocess.run(cmd, capture_output=True, text=True, timeout=timeout)
    except (OSError, subprocess.SubprocessError) as exc:
        log.warning("%s: %s", cmd[0], exc)
        return subprocess.CompletedProcess(cmd, 1, "", str(exc))


def _write(path: Path, value: str) -> None:
    try:
        path.write_text(value)
    except OSError as exc:
        log.warning("%s: %s", path, exc)


def _led_trigger() -> "str | None":
    """The LED's current mode: the name sysfs shows in brackets."""
    try:
        m = re.search(r"\[([^\]]+)\]", (ACT_LED / "trigger").read_text())
    except OSError:
        return None
    return m.group(1) if m else None


class System:
    def __init__(self) -> None:
        # What wake() gives the LED back: the mode enter() found. The Zero W
        # boots with "actpwr" (lit, dark on card access); "mmc0" (dark, lit on
        # card access) only stands in when this service starts already lean.
        self.led_trigger = "mmc0"

    def enter(self) -> None:
        log.info("standby: reconnect stopped, Bluetooth off, Wi-Fi off, CPU powersave, LED off")
        _run("systemctl", "stop", "blueandme-bt-reconnect.service")
        _run("bluetoothctl", "power", "off")
        _run("nmcli", "radio", "wifi", "off")
        _write(GOVERNOR, "powersave")
        found = _led_trigger()
        if found and found != "none":
            self.led_trigger = found
        _write(ACT_LED / "trigger", "none")
        _write(ACT_LED / "brightness", "0")

    def wake(self) -> None:
        start = time.monotonic()
        _write(GOVERNOR, "ondemand")
        _write(ACT_LED / "trigger", self.led_trigger)
        _run("bluetoothctl", "power", "on")
        page_phone()
        log.info("awake: phone paged %.1f s after the wake", time.monotonic() - start)
        _run("systemctl", "start", "blueandme-bt-reconnect.service")
        _run("nmcli", "radio", "wifi", "on")  # last, so it does not compete

    def power_off(self) -> None:
        log.info("hold over: halting; the ignition on GPIO3 or a power cycle starts it again")
        _run("systemctl", "poweroff")
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

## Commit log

2026-10-06 Blue&Me replacement for the Alfa Romeo Giulietta 940 on a Raspberry Pi Zero W
    The code behind https://duzgun.org/blog/giulietta-blue-me/: the application
    that answers the car as the Blue&Me node on B-CAN and bridges the phone's
    Bluetooth audio, calls and track text to the factory radio, with its
    installer, units, tests, the supervised bring-up scripts and the housing models.
    Prepared from the working repository for publication:
    - The car's PROXI value is a setting, can.proxi_value, empty by default; the
    node does not answer the challenge without it.
    - Recordings of the car, working notes and photos are left out.
    - Test data uses made-up phone numbers, addresses and records.
    - The Fiat Dob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
    [2026-09-25-buck-6-32v-usb.csv, 2026-09-25-halted-split-markers.csv, 2026-09-25-halted-split-power.csv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]
2026-10-06 packages: the bundled bluez-alsa package names this repository
    The package's control file named the repository it was first built in. Only
    that text is rewritten; the data part is byte for byte the same.
    Verified: dpkg-deb --info and --contents accept the package on Debian 13,
    and the data archive has the same checksum as before.
    Tests: python -m pytest -> 315 passed, 16 skipped (traces not fetched).
